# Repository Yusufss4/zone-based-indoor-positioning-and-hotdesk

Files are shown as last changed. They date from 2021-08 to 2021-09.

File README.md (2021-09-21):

[][contributors-url] [][forks-url] [][stars-url] [][issues-url]

<!-- PROJECT LOGO -->
<br/>
<p align="center">
  <a href="https://github.com/Yusufss4/Academy2021">
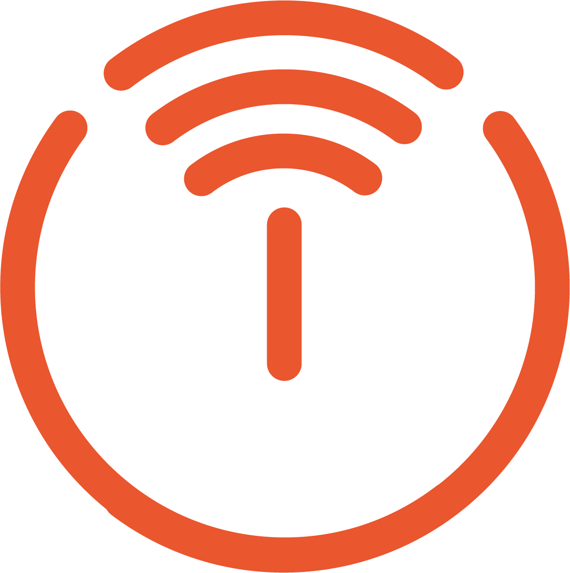
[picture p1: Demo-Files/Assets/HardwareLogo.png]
    
  </a>
  <h1 align="center">Intership Project Indoor Positioning and Hotdesk</h1>
  <p align="center">
    Borda Academy 2021 Project Co-Working Smart Office Hardware Part
    <br/>
    <a href="https://youtu.be/FV2so5sVpH8">Watch Video</a>
    ·
    <a href="https://github.com/Yusufss4/Academy2021/issues">Report Bug</a>
    ·
    <a href="https://github.com/Yusufss4/Academy2021/issues">Request Feature</a>
  </p>
   <p align="center">
    Index
    <br/>
    <a href="#about-the-project">About the Project</a>
    ·
    <a href="#products">Products</a>
    ·
    <a href="#Required-Parts-(BOM)">Part List</a>
        ·
    <a href="#How-to-Build-and-Run">How to Run</a>
            ·
      <a href="#MQTT-Connections-/-Topics">MQTT</a>
            ·
    <a href="#-Team-Behind-the-Hardware">Team</a>
  </p>
</p>

# About the Project

In this project there are three different task in the hardware section. These are;

 1. Capacity Calculation Per Room. Detecting a person if they are in the room and send information according to that.
 2. Capacity Calculation Per Office. Detecting a person if they are in the office or not using gateways. 
 3. Hotdesk and Meeting Room Scheduling. Controlling e-papers according to the information coming from the server. 
<p align="center">
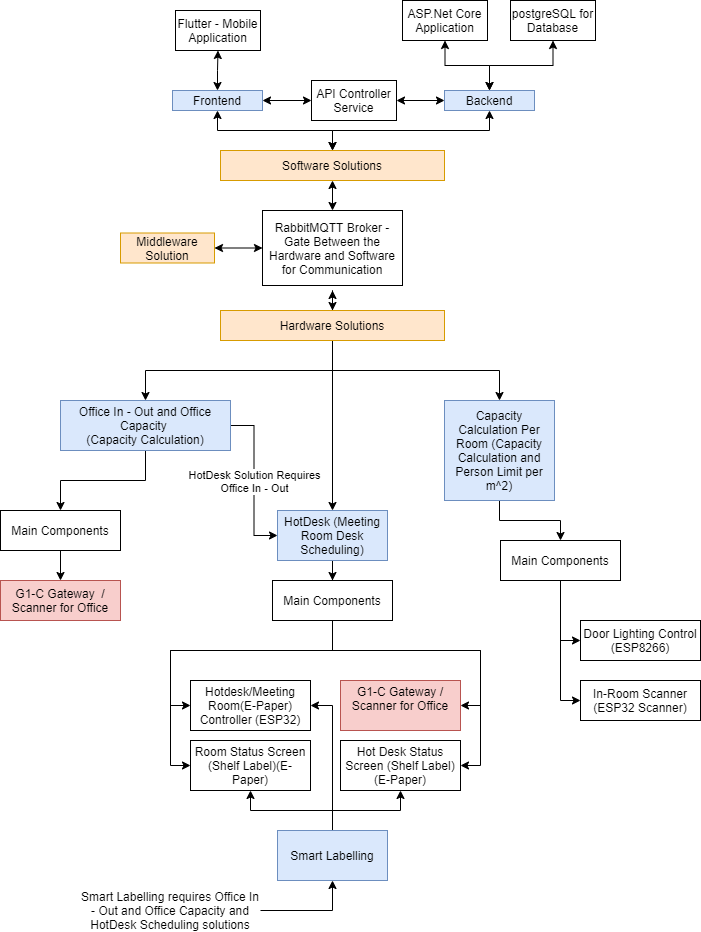
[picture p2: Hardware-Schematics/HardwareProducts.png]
Project Diagram

</p>

# Products

There are five different products in the project but only four of them can be coded and one of them can be only configured. 

## ESP32 In Room Scanner

### Explanation
ESP32 - In Room Scanner first scans the bluetooth devices and creates a buffer filled with RSSI signals and MAC addresses of the scanned devices. Later duplicate signals are being averaged and removed from the buffer and passed to the new buffer. Later in the publish MQTT function this buffer is transformed to JSON format and sent along with the MAC address of the device itself to differentiate the rooms (devices) from each other. This information will be processed by the server application and with the threshold value determined for each room the server will decide if the person is in the room and if it is in the room which person it is and send the number of people in the room information to the /nrom topic.

### Connection Diagram
<p align="center">
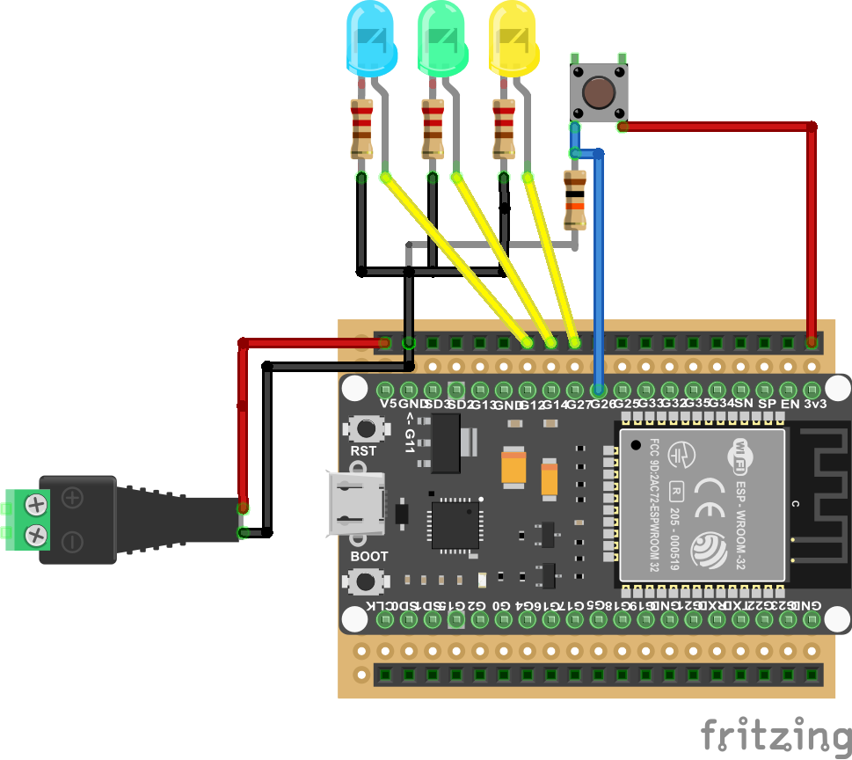
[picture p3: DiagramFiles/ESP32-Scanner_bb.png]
Connection Diagram
 
 </p>

### Box Design
<p align="center">
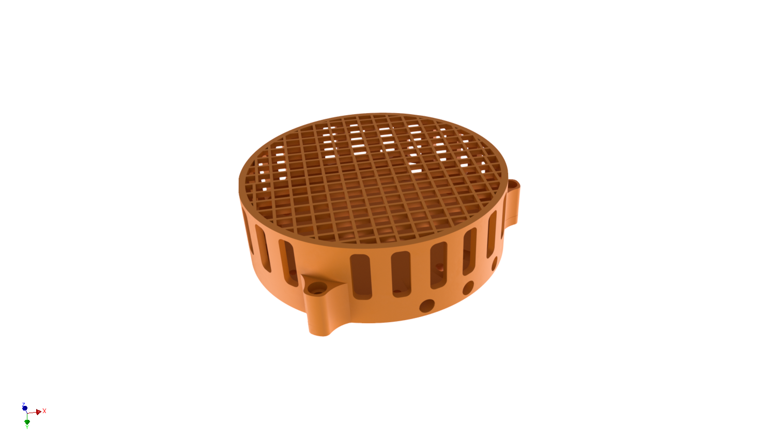
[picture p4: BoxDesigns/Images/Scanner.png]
Box Design

</p>

### Product
<p align="center">
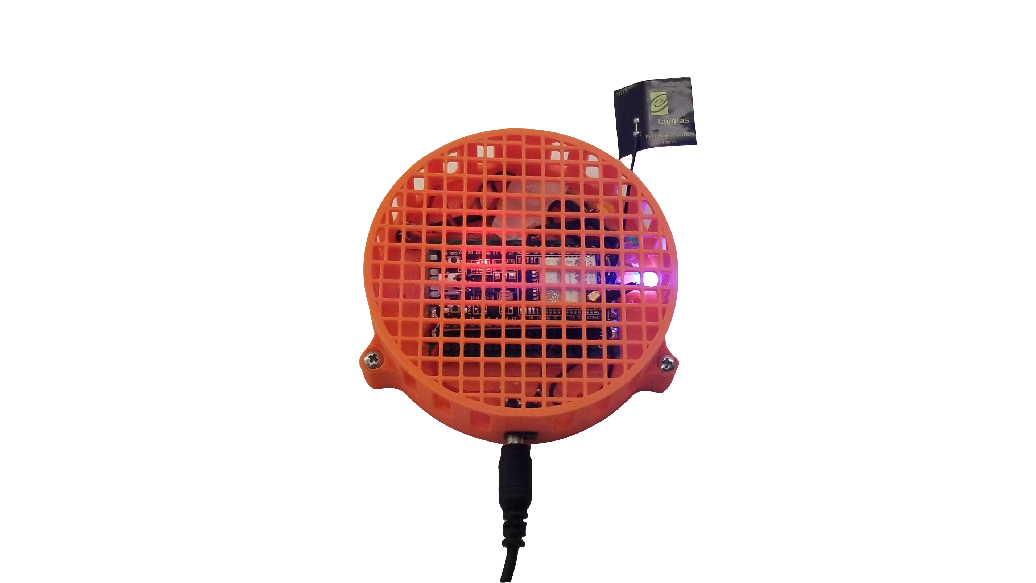
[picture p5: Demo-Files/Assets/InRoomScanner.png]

</p>
 
## ESP8266 Door Lighting Controller

ESP8266 always listens to the topic /nrom and whenever a message comes first by looking at the MAC addresses sent with the message it decides if the message is intended for it or not. If it is intended for that specific device according to the number of people information in the message it lights the NeoPixel LEDs. If the capacity is reached all LEDs will light in the color of red.

### Connection Diagram
<p align="center">
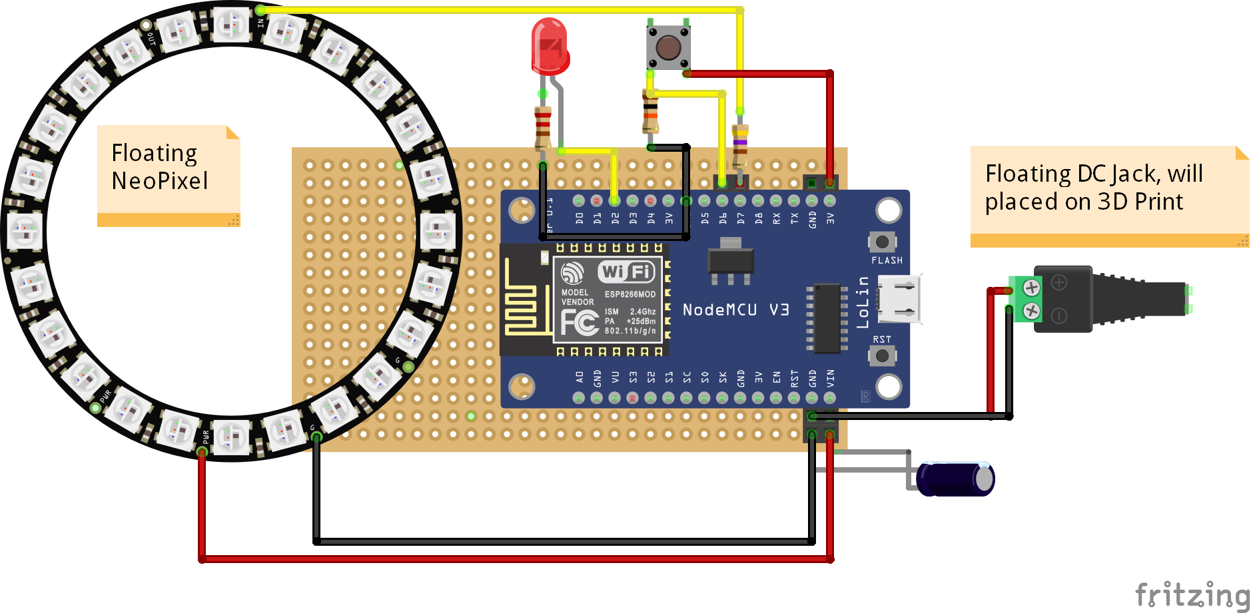
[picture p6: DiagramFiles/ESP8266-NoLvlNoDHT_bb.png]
ESP8266 Door Lighting Controller Connection Diagram
 
 </p>

### Box Design
<p align="center">
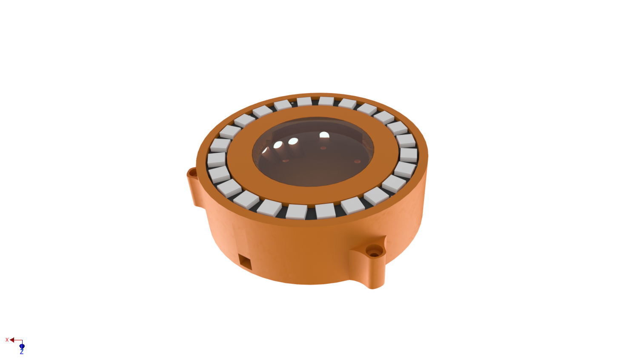
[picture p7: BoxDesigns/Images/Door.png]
ESP8266 Door Lighting Controller Box Design
 
</p>

### Product
<p align="center">
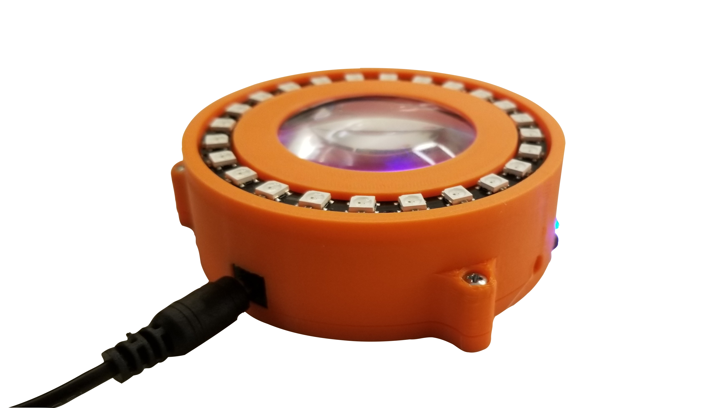
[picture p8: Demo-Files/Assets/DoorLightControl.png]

</p>

## ESP32 E-Paper Controller

E-paper controller ESP32 constantly listens to the publishments coming to the MQTT topic to which it is subscribed. When there is Publishment, it runs the bluetooth functions and does a scan. When it matches the UUID advertised by the shelf label with the UUID data received by MQTT, it establishes a connection with the shelf label. If the connection is successful, it sends the data to the electronic shelf label. If not, it will scan again and try to connect. MQTT sends a warning message to the broker if it cannot find a UUID value to match by scanning. 

### Connection Diagram
<p align="center">
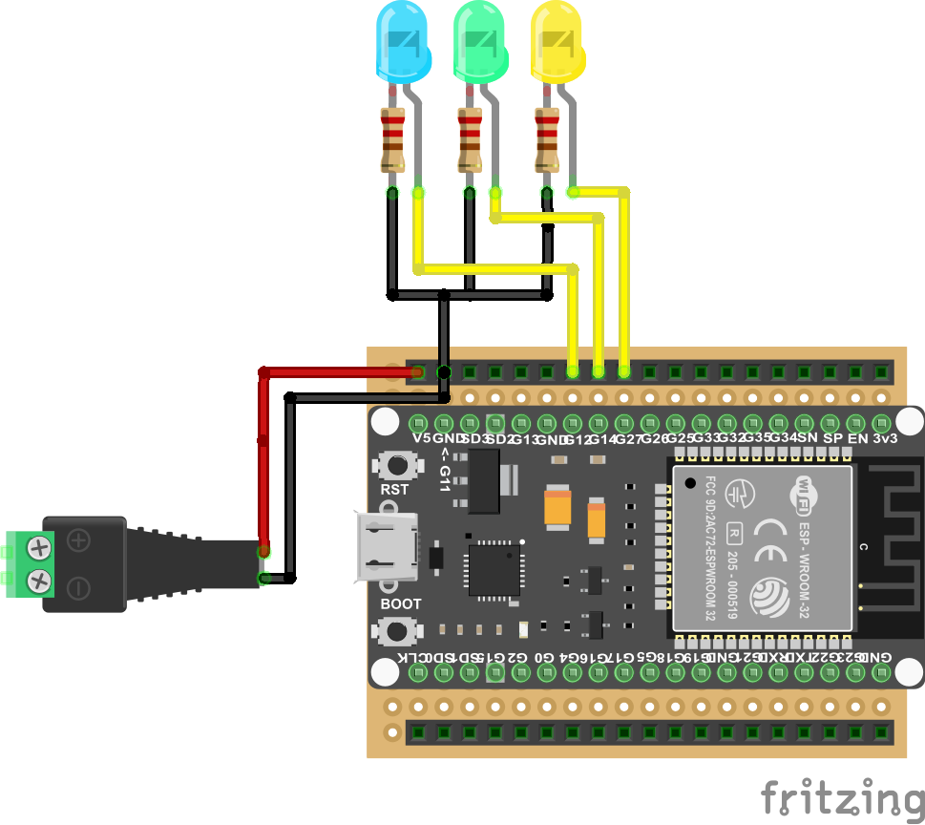
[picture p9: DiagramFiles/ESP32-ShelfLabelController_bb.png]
Connection Diagram
 
  </p>

### Box Design
<p align="center">
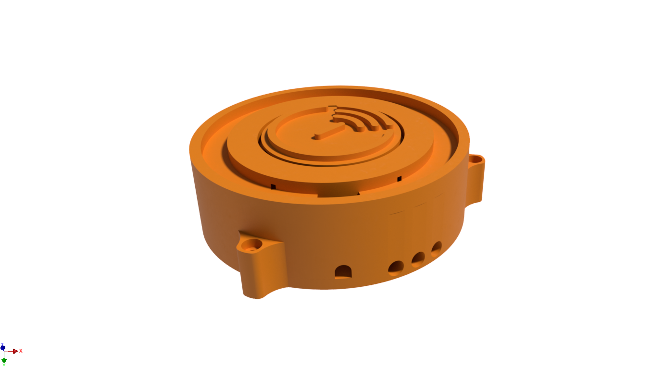
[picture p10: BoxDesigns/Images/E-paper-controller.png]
Box Design

 </p>

### Product
<p align="center">
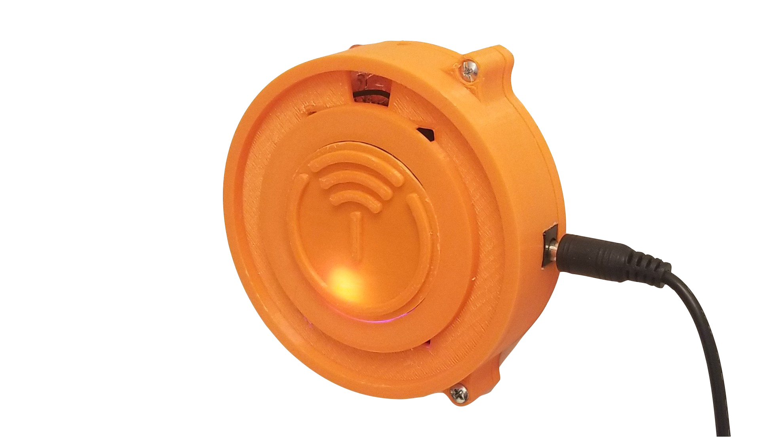
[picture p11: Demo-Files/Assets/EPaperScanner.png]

</p>

## E-Paper

Electronic Shelf Label is ready for a connection request by ESP32 by constantly making advertisements. The shelf labels used for the hot desk have two different screens. Reserved and Available screens. According to the data received by ESP32, the shelf label display is updated. The shelf labels used for the Meeting Room also have two different screens. Busy and Next event screens. According to the data received by ESP32, the shelf label display is updated.
### Screen Design
<p align="center">
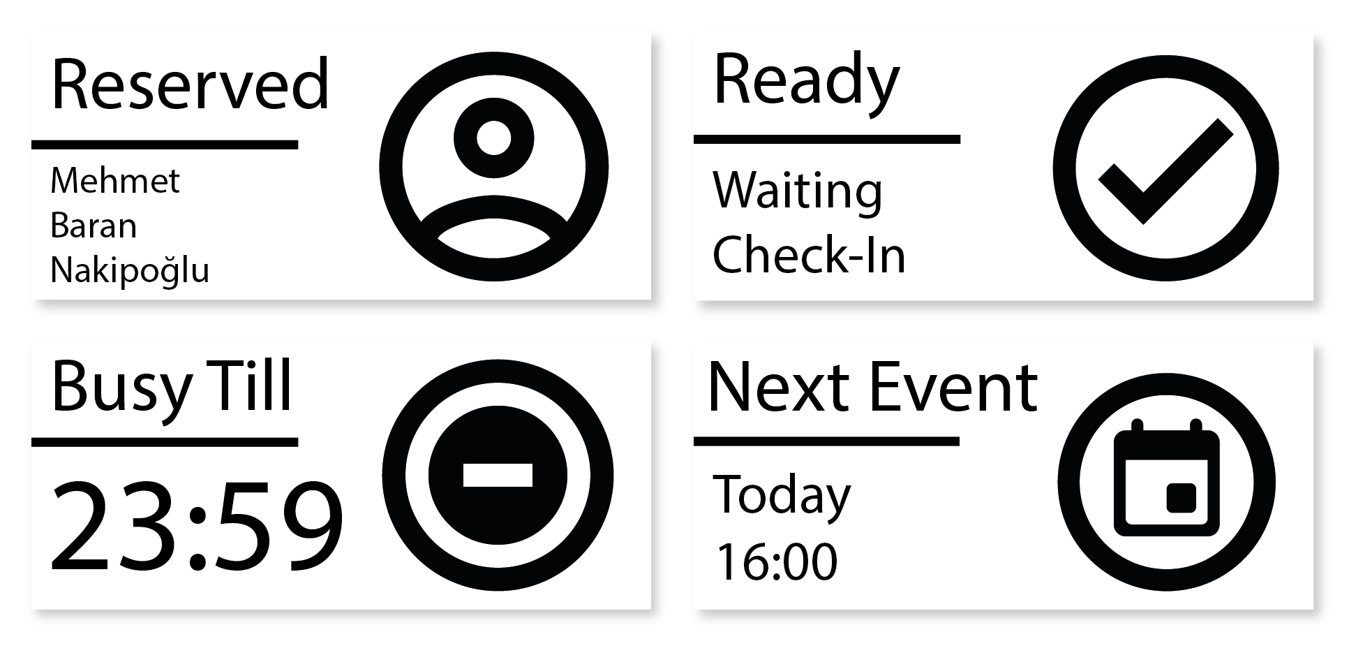
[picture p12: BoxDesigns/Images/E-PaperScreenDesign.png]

</p>

<!---
![resim](https://user-images.githubusercontent.com/44584158/132695852-41f96476-604e-4485-b37b-de702ea20266.png)

### Connection Diagram
<p align="center">
 <img src="images/logo.png" alt="E-Paper Connection Diagram" width="400">
 </p>
 -->

### Box Design
<p align="center">
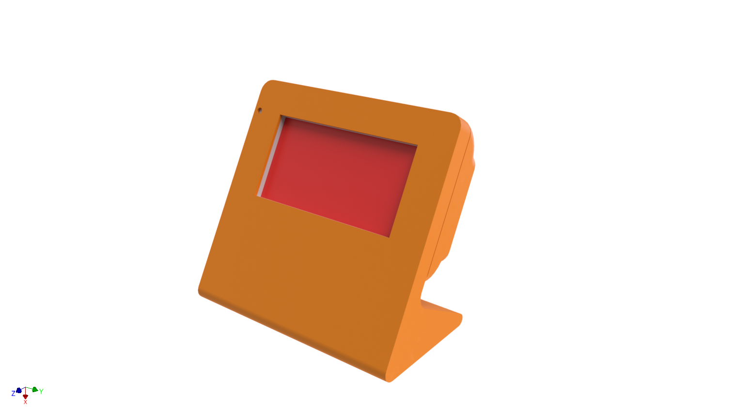
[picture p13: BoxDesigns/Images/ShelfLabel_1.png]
E-Paper Box Design

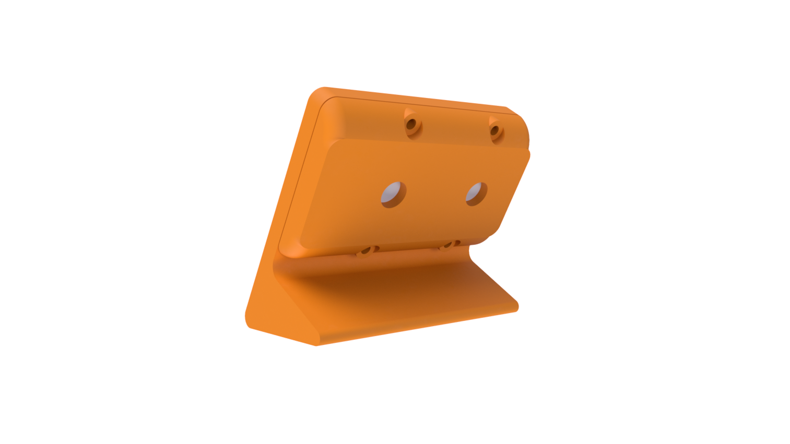
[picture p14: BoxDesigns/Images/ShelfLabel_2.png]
E-Paper Box Design

</p>

### Product
<p align="center">
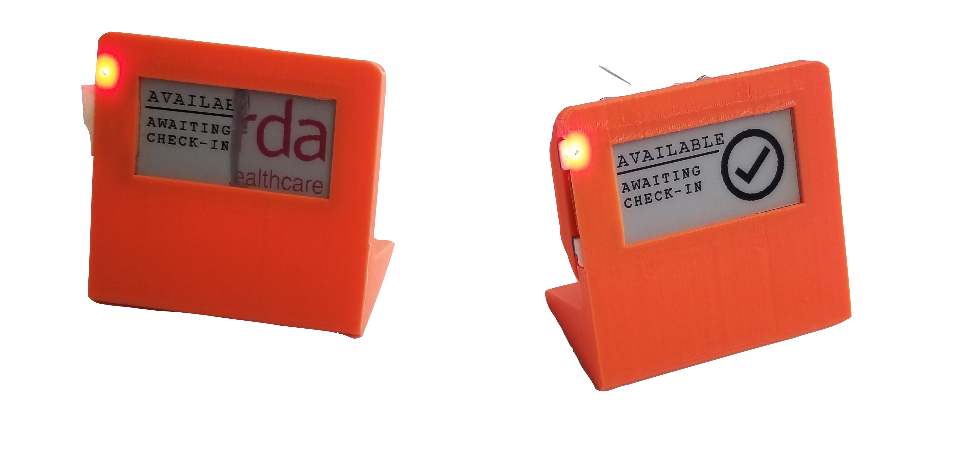
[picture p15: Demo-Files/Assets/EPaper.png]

</p>

# Required Parts (BOM)

All the required parts are determined for 2 Hotdesk, 2 Beacon, 2 Room and one Office. If you want to increase the number of rooms that you want to install you have to multiply the ESP8266 Door Light and ESP32 In Room Scanner equipments by two. Each room has one ESP8266 and one ESP32.

## BOM For ESP8266 Door Lighting Controller

| Name | How | Piece | How Many | Where |
|---|---|---|---|---|
| ESP32 | Main Controller | 1 | 1 Per Room/Device | Near the door |
| NeoPixel 24 Ring | Capacity Indicator | 1 | 1 Per Room/Device | Near the door |
| 5V Adapter | Power for ESP32 | 1 | 1 Per Room/Device | Near the door |
| 4x6cm Soldering Prototype Board | ESP32 Placement | 1 | 1 Per Room/Device | Near the door |
| 470R 1/4W Resistor | NeoPixel Signal Resistor | 1 | 1 Per Room/Device | Near the door |
| 5.5x2.21mm DC Power Jack | Power for ESP32 | 1 | 1 Per Room/Device | Near the door |
| 1x40 Male Header 80 Pin 90 Degree | ESP32 Placement | 1 | 1 Per Room/Device | Near the door |
| 1x40 Female Header 40 Pin 180 Degree | ESP32 Placement | 1 | 1 Per Room/Device | Near the door |
| 1000uF Capacitor | NeoPixel Current Protection | 1 | 1 Per Room/Device | Near the door |
| 6x6x5 Push Button | WiFi Access Point Reset | 1 | 1 Per Room/Device | Near the door |
| Blue LED | MQTT Indicator | 1 | 1 Per Room/Device | Near the door |
| 3D Printed Box Upper-Piece | Box Upper | 1 | 1 Per Room/Device | Near the door |
| 3D Printed Box Lower-Piece | Box Base Plate | 1 | 1 Per Room/Device | Near the door |
| 50mm Lens or Glass | To See Onboard Leds | 1 | 1 Per Room/Device | Near the door |

## BOM For ESP32 - In Room Scanner
| Name | How | Piece | How Many | Where |
|---|---|---|---|---|
| ESP32 DevkitV4 | Main Controller | 1 | 1 Per Room/Device | Inside the Room |
| ESP32 Taoglas 2.4Ghz | External Antenna for ESP32 | 1 | 1 Per Room/Device | Inside the Room |
| 5V Adapter | Power for ESP32 | 1 | 1 Per Room/Device | Inside the Room |
| 4x6cm Soldering Prototype Board | ESP32 Placement | 1 | 1 Per Room/Device | Inside the Room |
| 5.5x2.21mm DC Power Jack | Power for ESP32 | 1 | 1 Per Room/Device | Inside the Room |
| 1x40 Male Header 80 Pin 90 Degree | ESP32 Placement | 1 | 1 Per Room/Device | Inside the Room |
| 1x40 Female Header 40 Pin 180 Degree | ESP32 Placement | 1 | 1 Per Room/Device | Inside the Room |
| 6x6x5 Push Button | WiFi Access Point Reset | 1 | 1 Per Room/Device | Inside the Room |
| LEDs | Status LEDs | 3 | 1 Per Room/Device | Inside the Room |
| 3D Printed Box Upper-Piece | Box Upper | 1 | 1 Per Room/Device | Inside the Room |
| 3D Printed Box Lower-Piece | Box Base Plate | 1 | 1 Per Room/Device | Inside the Room |

## BOM For ESP32 - E-Paper Controller
| Name | How | Piece | How Many | Where |
|---|---|---|---|---|
| ESP32 DevkitV4 | Main Controller | 1 | 1 Per Room/Device | Inside the Room |
| 5V Adapter | Power for ESP32 | 1 | 1 Per Room/Device | Inside the Room |
| 4x6cm Soldering Prototype Board | ESP32 Placement | 1 | 1 Per Room/Device | Inside the Room |
| 5.5x2.21mm DC Power Jack | Power for ESP32 | 1 | 1 Per Room/Device | Inside the Room |
| 1x40 Male Header 80 Pin 90 Degree | ESP32 Placement | 1 | 1 Per Room/Device | Inside the Room |
| 1x40 Female Header 40 Pin 180 Degree | ESP32 Placement | 1 | 1 Per Room/Device | Inside the Room |
| 6x6x5 Push Button | WiFi Access Point Reset | 1 | 1 Per Room/Device | Not Added Yet |
| LEDs | Status LEDs | 3 | 1 Per Room/Device | Not Added Yet |
| 3D Printed Box Upper-Piece | Box Upper | 1 | 1 Per Room/Device | Inside the Room |
| 3D Printed Box Lower-Piece | Box Base Plate | 1 | 1 Per Room/Device | Inside the Room |

## Other Parts
| Name | How | Piece | How Many | Where |
|---|---|---|---|---|
| MTag2901 2.9" ESL Tag  | Room Status Screen | 1 | 1 per Room | Near the door |
| MTag2901 2.7" ESL Tag  | Hotdesk Status Screen | 2 | 1 per Table | On the table |
| CR2450 3V Battery | Battery for ESL | 2 | 2 per ESL | In ESL |
| CR2477 3V Battery | Battery for E7 Beacon | 2 | 1 per People | In Beacon |
| G1-C Gateway | BLE Office Covarage | 1 | 1 per Office | Middle of Office |
| E7 Plus Beacon | BLE Advertisement | 2 | 1 per People | On People's Pocket |
| Extension cable | To Extend Power | 2 | As you require | Near Power |

# How to Build and Run

## ESP32 In-Room Scanner and ESP8266 Door Light Controller
1. You can run the project without all the Leds, power adapters, buttons, cables etc. just by uploading code to the necessary controller boards like ESP32 and ESP8266.
2. Download the code for each device. Each document is divided in the files too.
3. Download the ESP32 and ESP8266 Packages for board manager in Arduino IDE.
4. For ESP32 click Tools->Partition Scheme->Huge APP (3MB/No OTA) so that code can compile.
5. You have to use a MQTT Broker for publishing and subscribing topics. From the MQTT Config change the connections to whatever broker you are using.
6. If you are using a broker that requires a certificate uncomment the certificate and transform the **WifiClient** to **WiFiClientSecure**so that ESP32 or ESP8266 can transfer the certificates. ,
7. Pull the Button Pin to the 3.3V if you did not connect the button so that WiFi manager does not reset the WiFi credentials.
8. ESP32 In-Room Scanner and ESP8266 uses WifiManager so to connect the devices to the WiFi, if the device is not connected the Access Point will be opened, first you should connect to the wifi network created by device, name will be Fora - [Mac Address of Device] and later a web page application will be opened if you connect to that Access Point. Later you can connect to any wifi.
9. After connecting both ESP32 and ESP8266 to WiFi and MQTT Broker you can test the device using the MQTTLens application.
10. If you made all the connections like buttons, leds, neopixel etc. you can test the PCB by running the code PCBTester in the Demo files.

## ESP32 E-Paper Controller and E-Paper

1.
2.

# MQTT Connections / Topics

 - Topic and Data Type documentation can be reached from [here.](https://docs.google.com/document/d/1uNCvFoLJsAC_Qh4L8_6ozjhal6APVGUYTeoTuyXoGE8/edit?usp=sharing)
 - To connect the devices you have to use a MQTT Broker. For the connections steps please follow How to Run steps.
>Some of the alternatives for the MQTT Broker: 
> - Deployed RabbitMQ 
> - Adafruit IO
> - EMQX
> - HiveMQ (Not Stable)

General Diagram showing the communication can be seen below.
<p align="center">
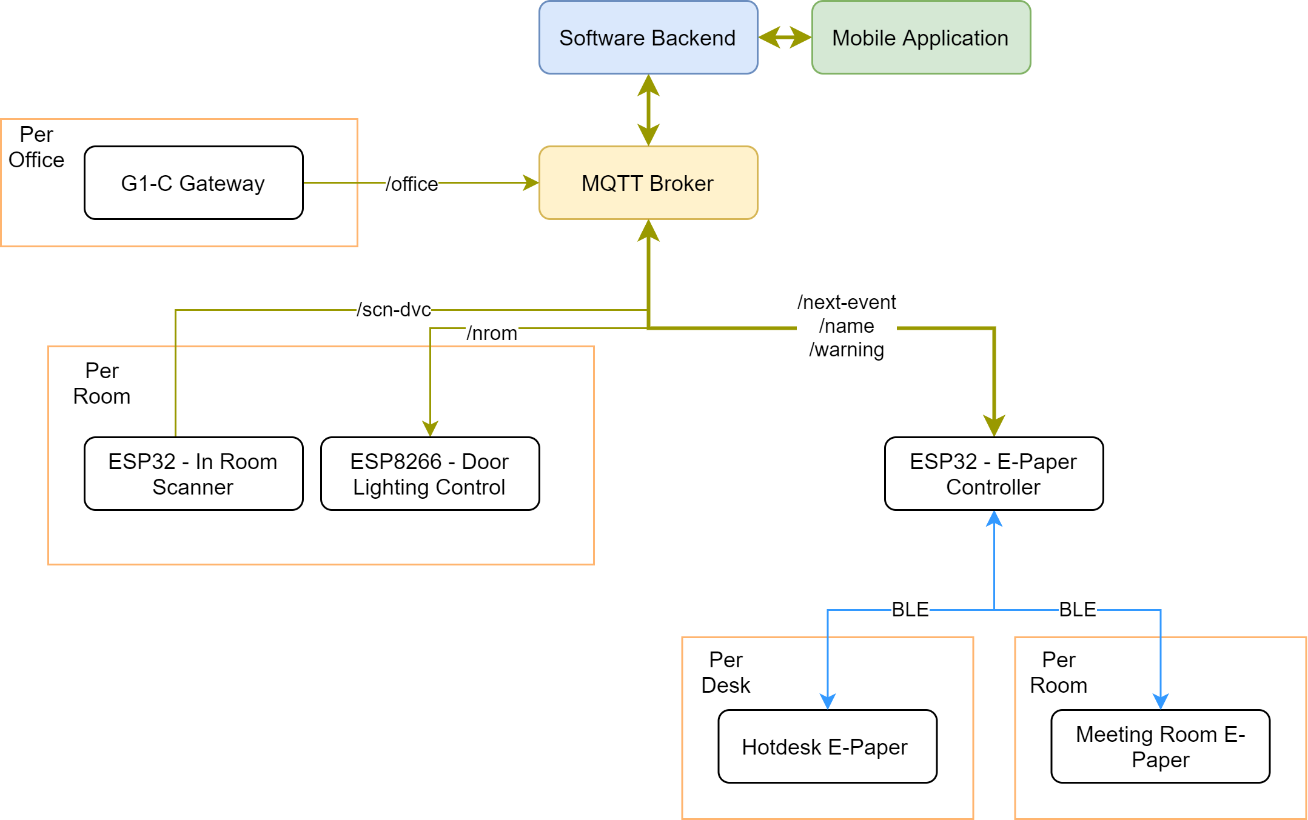
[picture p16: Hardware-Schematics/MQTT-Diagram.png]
MQTT Diagram

</p>

# Team Behind the Hardware

<p align="center">
<a href="https://www.linkedin.com/in/yusufss/">
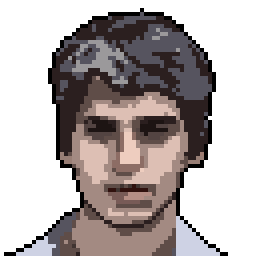
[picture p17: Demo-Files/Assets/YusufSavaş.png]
Yusuf Savaş
  </a> 
 <a href="https://www.linkedin.com/in/utkuurkun/">
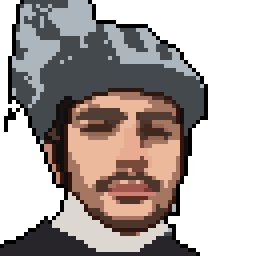
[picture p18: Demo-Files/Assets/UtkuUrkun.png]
Utku Urkun
   </a>
  <a href="https://www.linkedin.com/in/ata-korkusuz-77707118b/">
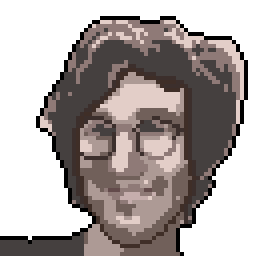
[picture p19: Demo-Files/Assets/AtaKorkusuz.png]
Ata Korkusuz
   </a>
</p>

<p align="center">
<a href="https://www.linkedin.com/in/berkay-arslan-3b9b95141/">
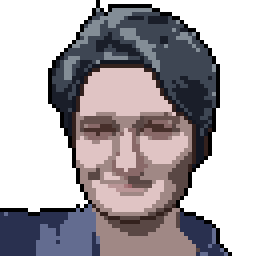
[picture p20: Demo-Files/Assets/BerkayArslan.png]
Berkay Arslan
   </a> 
  <a href="https://www.linkedin.com/in/zeynepbilge/">
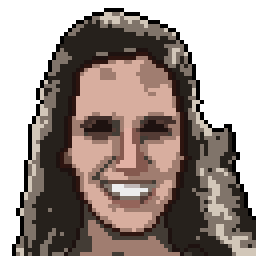
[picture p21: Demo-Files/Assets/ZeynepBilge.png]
Zeynep Bilge
   </a>
  <a href="https://www.linkedin.com/in/emine-acar-8036639b/">
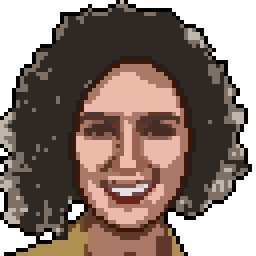
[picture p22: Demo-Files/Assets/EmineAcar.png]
Emine Acar
   </a>
</p>

<p align="center">
<a href="https://www.linkedin.com/in/eymen-topcuoglu/">
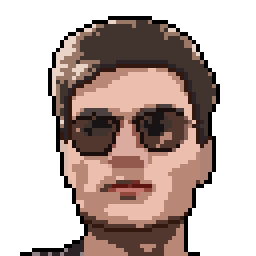
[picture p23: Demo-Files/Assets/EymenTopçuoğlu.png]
Eymen Topçuoğlu
   </a>
</p>

<!-- MARKDOWN LINKS & IMAGES -->
<!-- https://www.markdownguide.org/basic-syntax/#reference-style-links -->
[contributors-shield]: https://img.shields.io/github/contributors/Yusufss4/Academy2021.svg?style=for-the-badge
[contributors-url]: https://github.com/Yusufss4/Academy2021/graphs/contributors
[forks-shield]: https://img.shields.io/github/forks/Yusufss4/Academy2021.svg?style=for-the-badge
[forks-url]: https://github.com/Yusufss4/Academy2021/network/members
[stars-shield]: https://img.shields.io/github/stars/Yusufss4/Academy2021.svg?style=for-the-badge
[stars-url]: https://github.com/Yusufss4/Academy2021/stargazers
[issues-shield]: https://img.shields.io/github/issues/Yusufss4/Academy2021.svg?style=for-the-badge
[issues-url]: https://github.com/Yusufss4/Academy2021/issues
[license-shield]: https://img.shields.io/github/license/Yusufss4/Academy2021.svg?style=for-the-badge
[license-url]: https://github.com/Yusufss4/Academy2021/blob/master/LICENSE.txt
[linkedin-shield]: https://img.shields.io/badge/-LinkedIn-black.svg?style=for-the-badge&logo=linkedin&colorB=555
[linkedin-url]: https://linkedin.com/in/yusufss
[product-screenshot]: images/screenshot.png

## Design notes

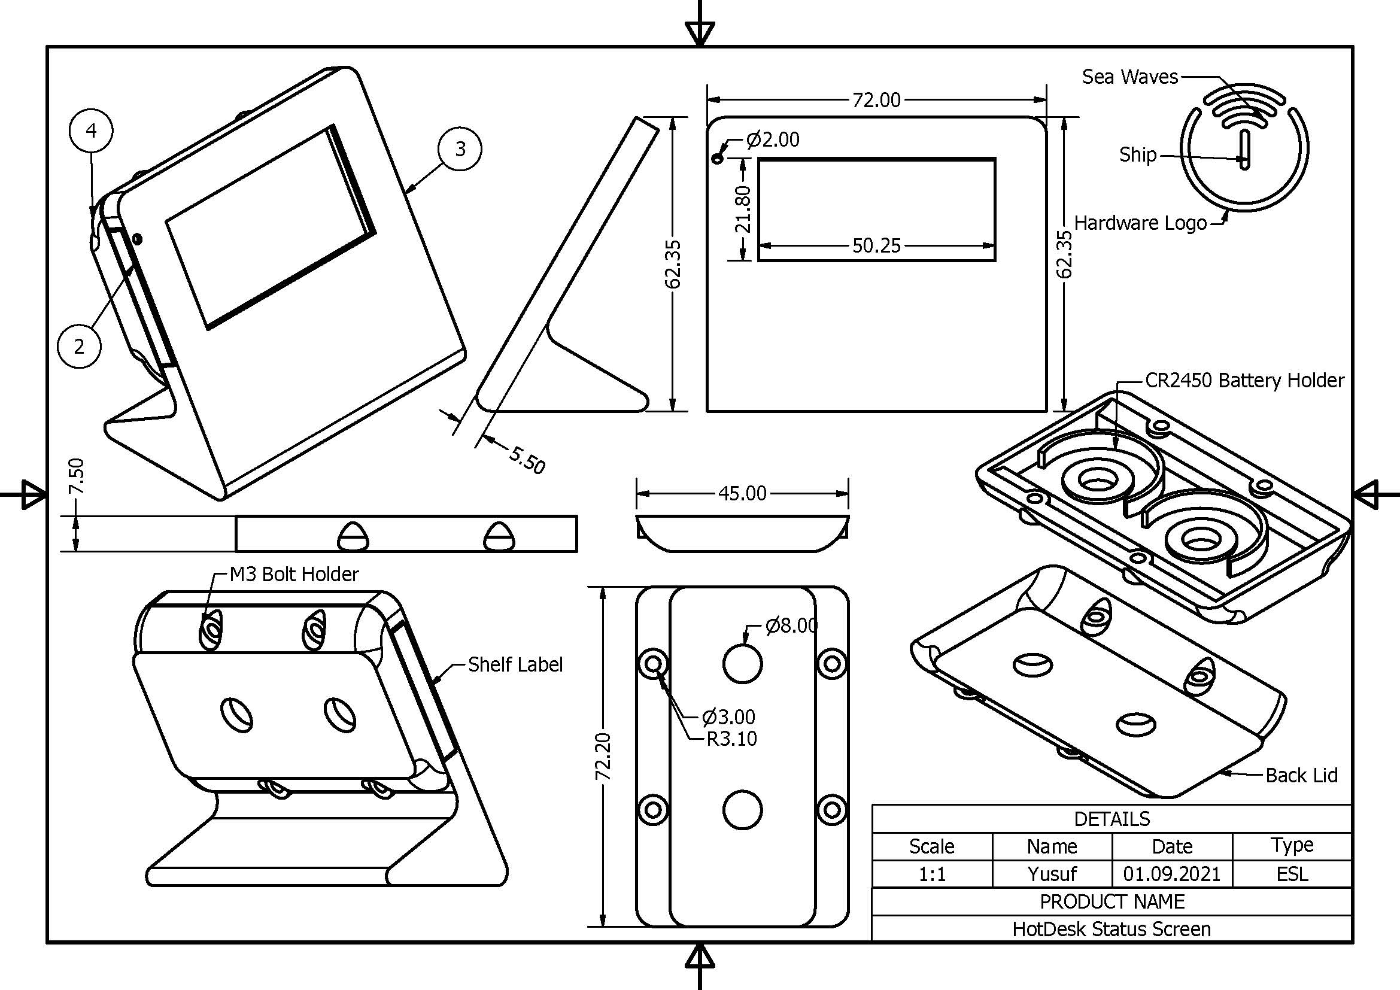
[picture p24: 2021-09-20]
BoxDesigns/Images/ShelfLabel.jpg

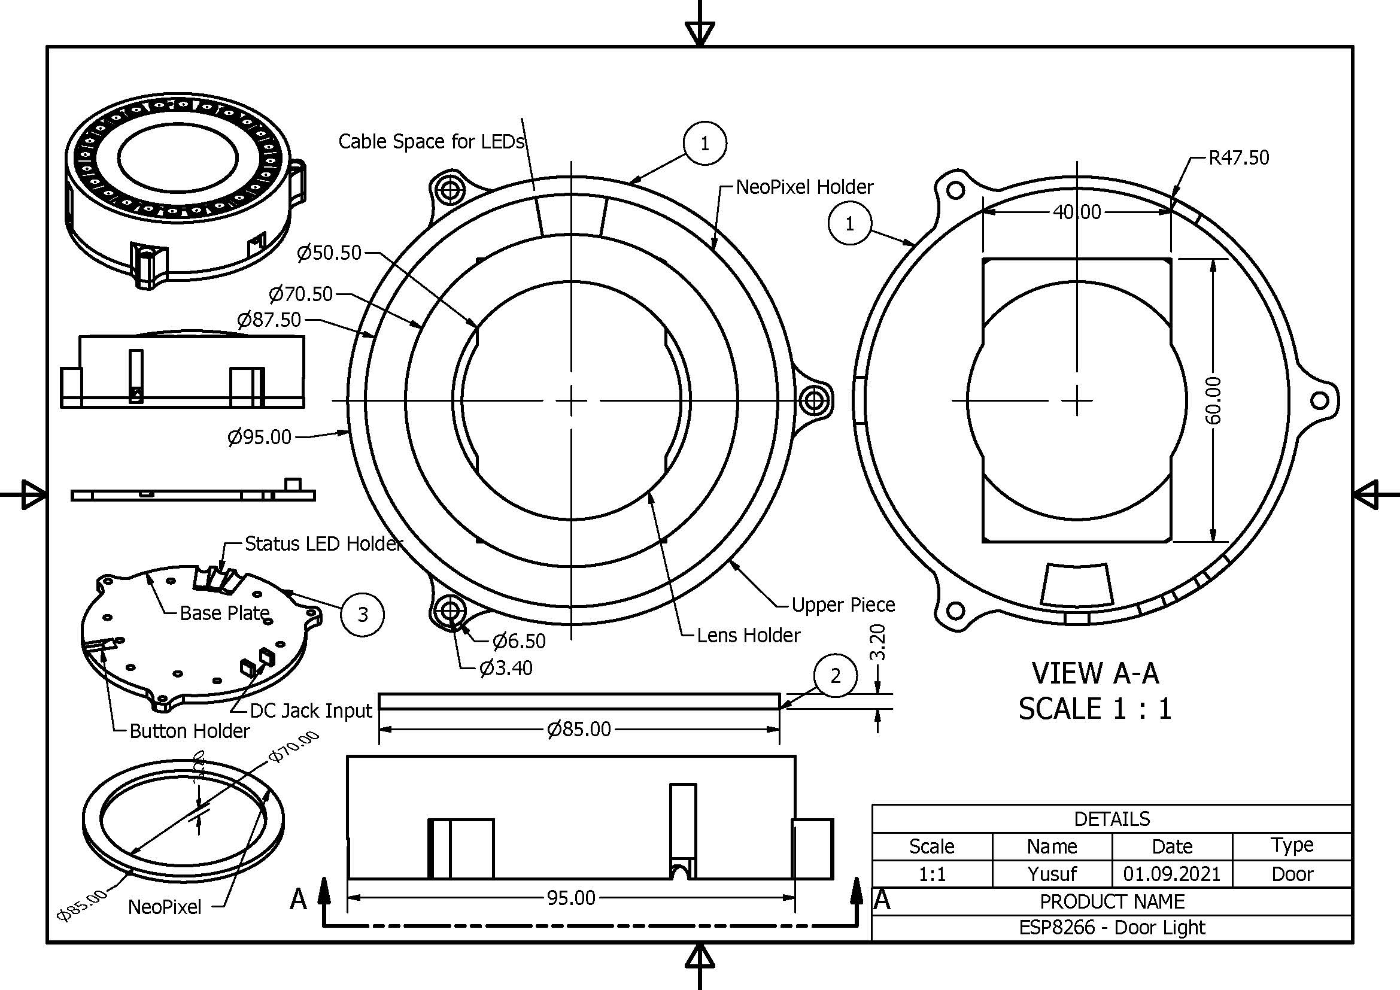
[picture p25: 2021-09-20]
BoxDesigns/Images/ESP8266-Door.jpg

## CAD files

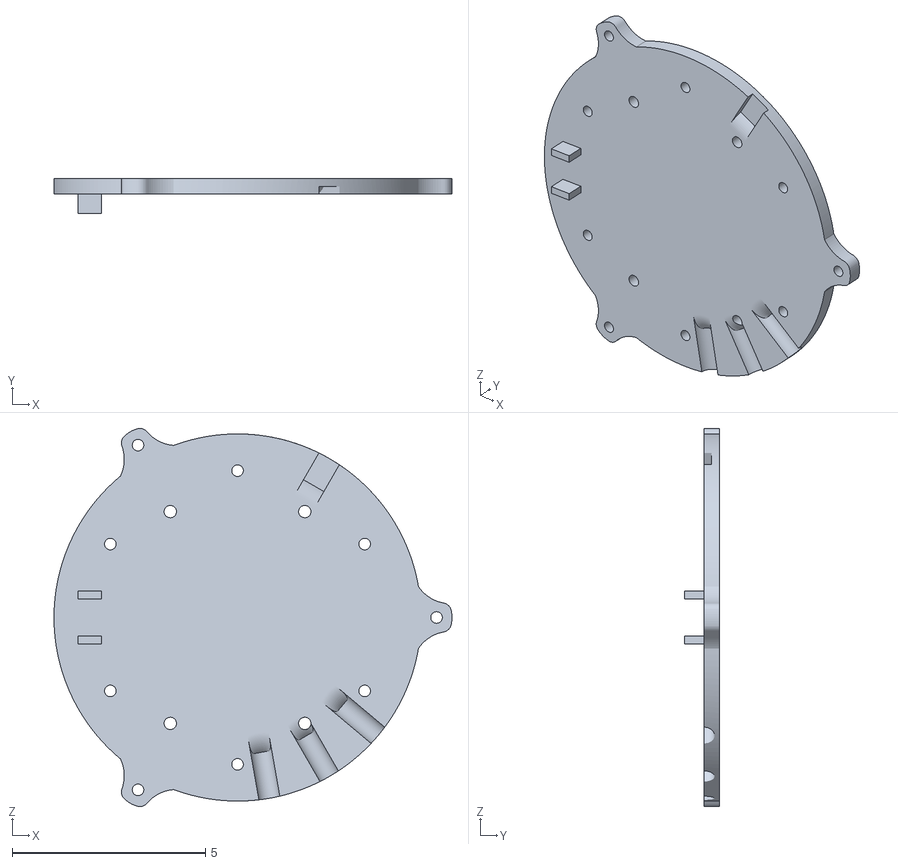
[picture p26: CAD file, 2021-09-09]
BoxDesigns/ESP32-Scanner/Scanner-BottomPart.stl
10.3 x 0.9 x 9.79

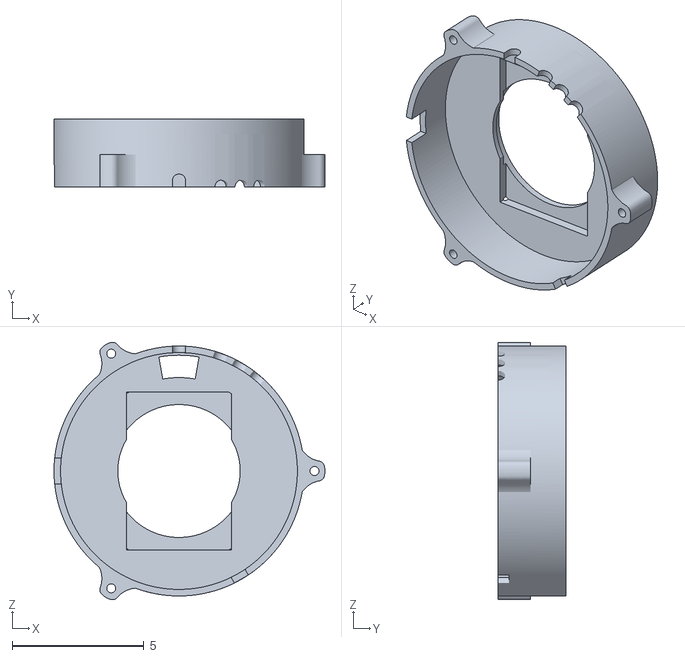
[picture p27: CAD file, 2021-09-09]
BoxDesigns/ESP8266-Door/Door-TopPart_MirrorV3.stl
10.3 x 2.60 x 9.79

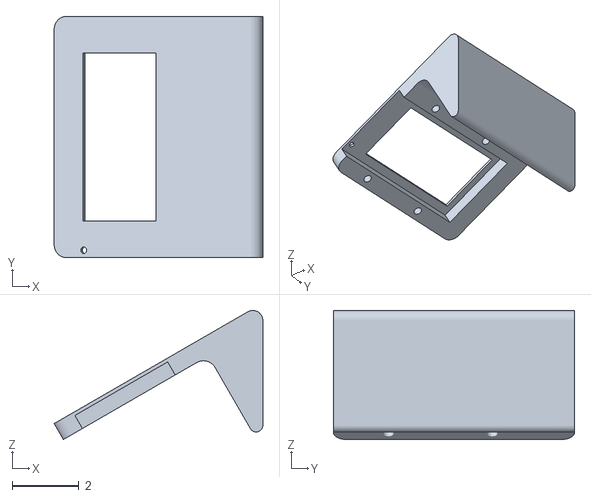
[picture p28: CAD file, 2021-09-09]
BoxDesigns/ShelfLabel/ShelfLabelStandV2.stl
6.24 x 7.20 x 3.86

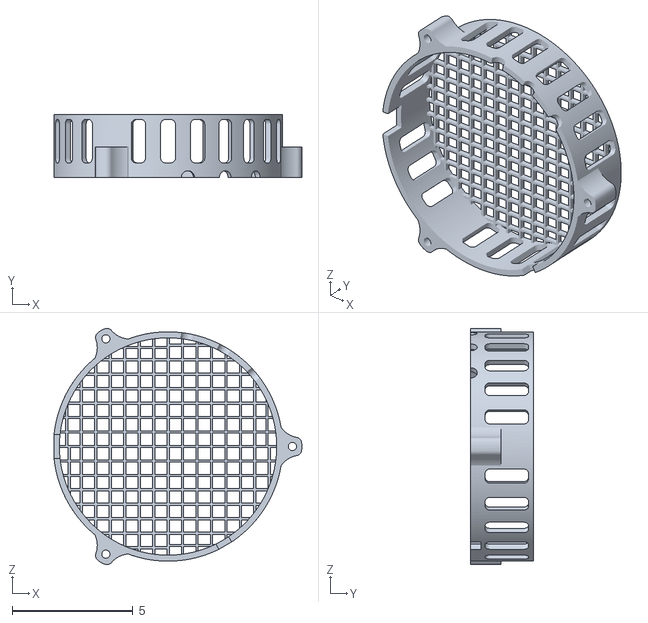
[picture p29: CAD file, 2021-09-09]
BoxDesigns/ESP32-Scanner/Scanner-TopPartV2_MirrorV2.stl
10.3 x 2.60 x 9.79

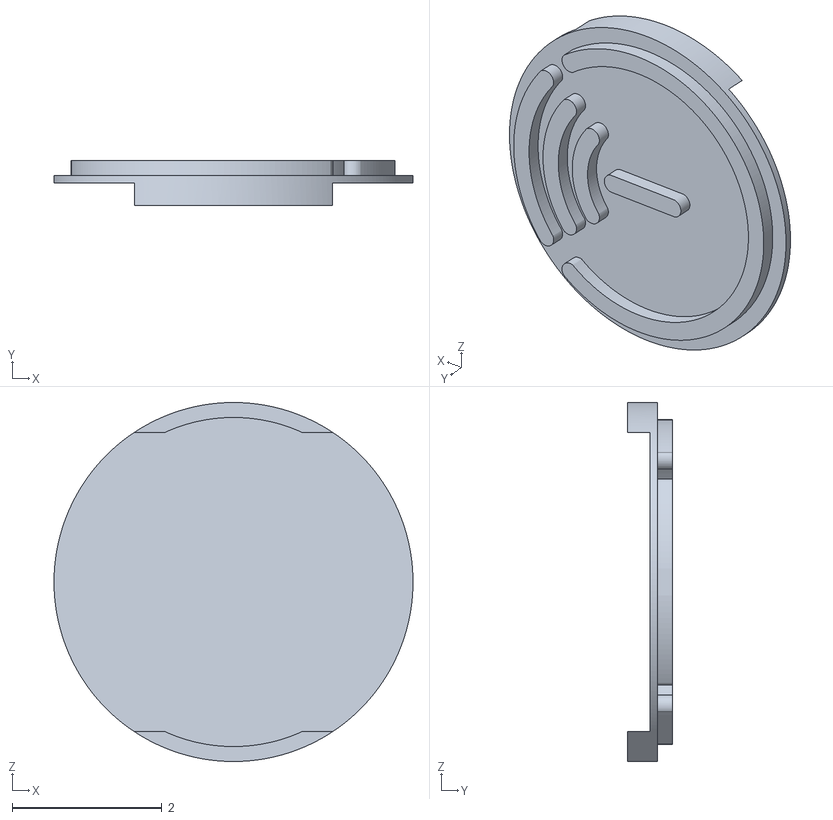
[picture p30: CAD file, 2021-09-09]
BoxDesigns/ShelfLabel/Scanner-Kapak.stl
4.80 x 0.6 x 4.80

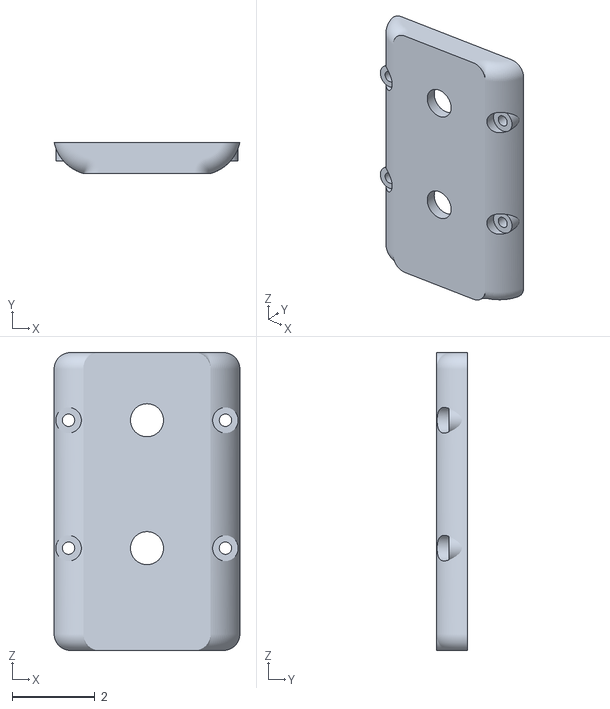
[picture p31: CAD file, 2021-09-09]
BoxDesigns/ShelfLabel/ShelfLabel-Kapak.stl
4.50 x 0.75 x 7.22

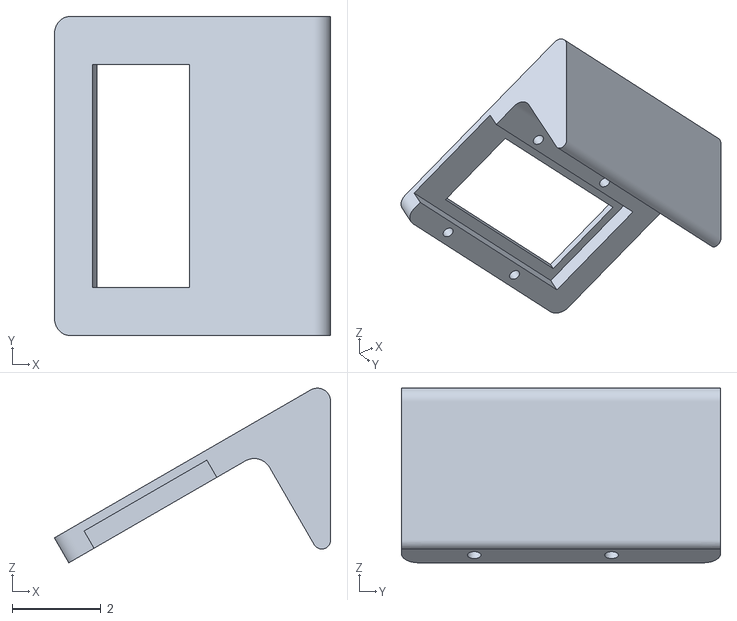
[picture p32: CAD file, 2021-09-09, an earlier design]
BoxDesigns/ShelfLabel/ShelfLabelStandV1.stl
6.24 x 7.20 x 3.94

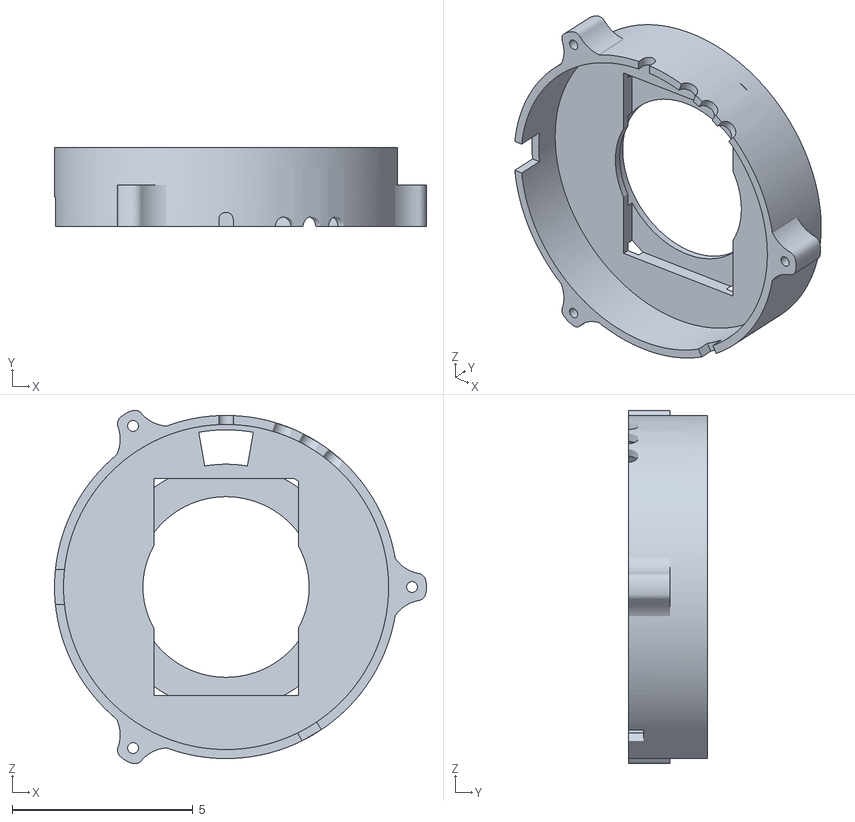
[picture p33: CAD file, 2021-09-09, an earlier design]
BoxDesigns/ESP8266-Door/Door-TopPart_MirrorV2.stl
10.3 x 2.20 x 9.79

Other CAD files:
BoxDesigns/ESP32-Scanner/Scanner-Assembly.dwg
BoxDesigns/ESP8266-Door/ESP8266-Door.dwg
BoxDesigns/ShelfLabel/ShelfLabel.dwg
BoxDesigns/ESP8266-Door/Door-BottomPart.stl
BoxDesigns/ESP32-Scanner/OldVersions/Scanner-Assembly.0004.dwg
BoxDesigns/ESP8266-Door/OldVersions/ESP8266-Door.0001.dwg
BoxDesigns/ShelfLabel/OldVersions/ShelfLabel.0002.dwg
BoxDesigns/ESP32-Scanner/OldVersions/Scanner-Assembly.0002.iam
BoxDesigns/ESP32-Scanner/OldVersions/Scanner-BottomPart.0004.ipt
BoxDesigns/ESP32-Scanner/OldVersions/Scanner-Kapak.0003.ipt
BoxDesigns/ESP32-Scanner/OldVersions/Scanner-TopPart.0016.ipt
BoxDesigns/ESP32-Scanner/OldVersions/Scanner-TopPartV2.0002.ipt
BoxDesigns/ESP32-Scanner/Scanner-Assembly.iam
BoxDesigns/ESP32-Scanner/Scanner-BottomPart.ipt
BoxDesigns/ESP32-Scanner/Scanner-Electronics.ipt
BoxDesigns/ESP32-Scanner/Scanner-TopPart.ipt
BoxDesigns/ESP32-Scanner/Scanner-TopPartV2.ipt
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

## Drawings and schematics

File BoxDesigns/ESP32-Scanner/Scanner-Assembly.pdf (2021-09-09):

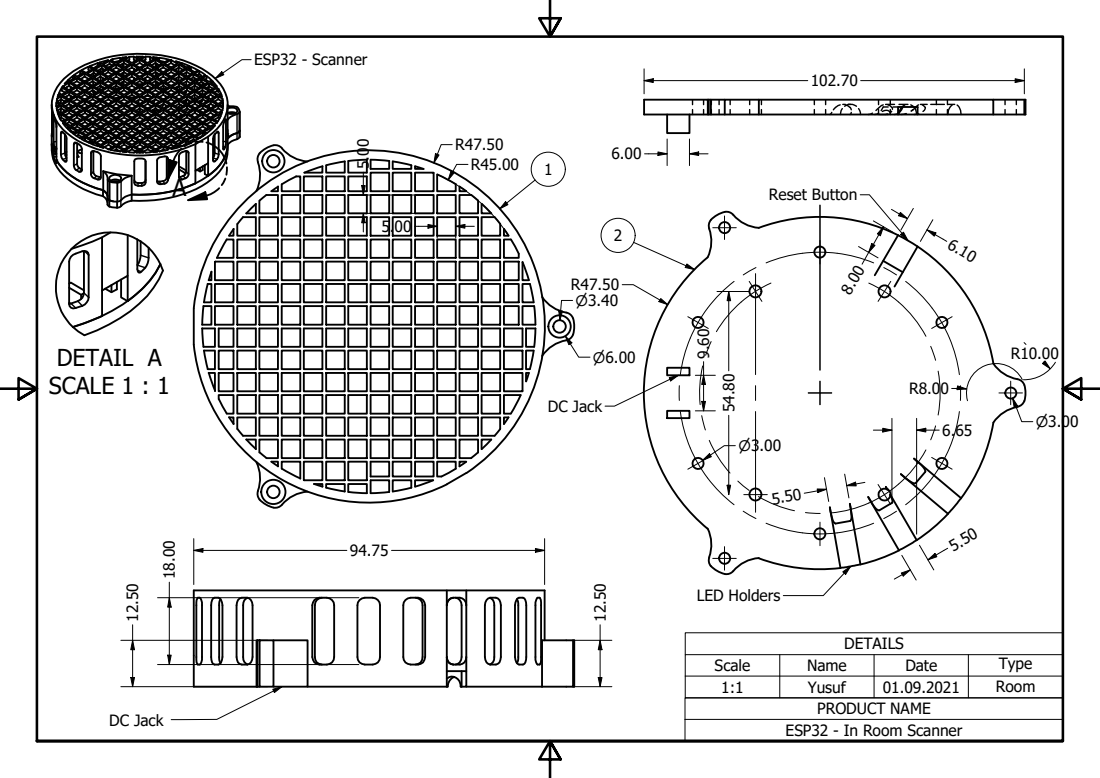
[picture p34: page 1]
DETAIL A SCALE 1 : 1; ESP32 - Scanner; LED Holders; DC Jack; Reset Button

Scale | Name | Date | Type
1:1 | Yusuf | 01.09.2021 | Room

PRODUCT NAME
ESP32 - In Room Scanner

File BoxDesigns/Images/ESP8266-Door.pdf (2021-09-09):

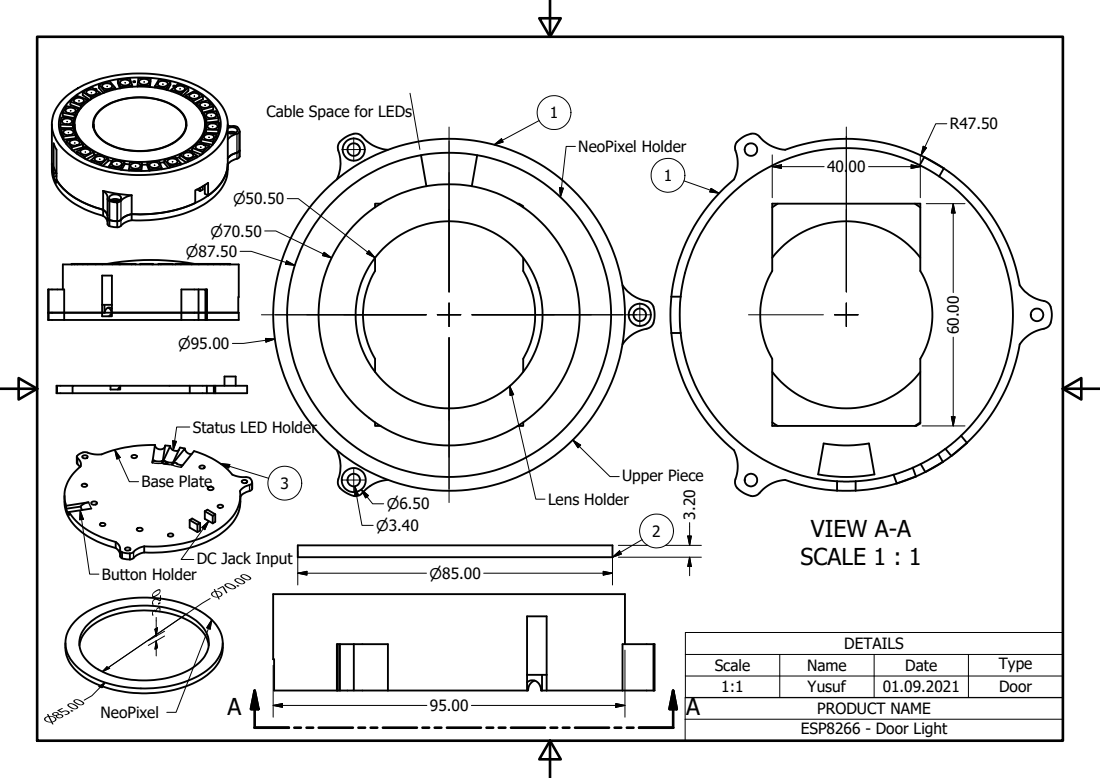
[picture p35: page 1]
VIEW A-A SCALE 1 : 1; DETAILS; PRODUCT NAME ESP8266 - Door Light; NeoPixel; Base Plate; Upper Piece; Lens Holder; NeoPixel Holder; Button Holder

Cable Space for LEDs

Status LED Holder

DC Jack Input

Scale | Name | Date | Type
1:1 | Yusuf | 01.09.2021 | Door

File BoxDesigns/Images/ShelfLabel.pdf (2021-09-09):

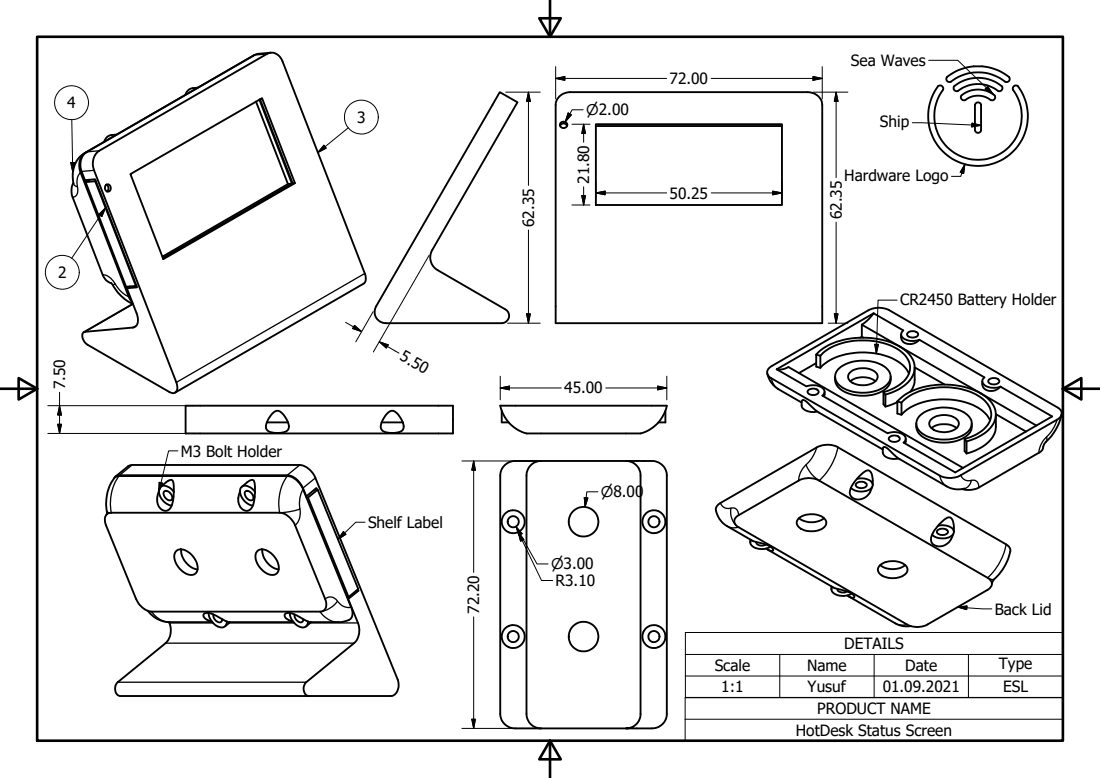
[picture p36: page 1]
DETAILS; CR2450 Battery Holder; Back Lid; Shelf Label; M3 Bolt Holder; Hardware Logo; Ship; Sea Waves

Scale | Name | Date | Type
1:1 | Yusuf | 01.09.2021 | ESL

PRODUCT NAME
HotDesk Status Screen

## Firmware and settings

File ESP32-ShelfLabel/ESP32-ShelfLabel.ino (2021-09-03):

//Change Config File to Connect the MQTT Broker and WiFi
#include <Arduino.h>
#include <WiFi.h>
#include <PubSubClient.h>
#include "MQTT_Config.h"
#include "BLEDevice.h"
#include <Dictionary.h>


//dictionary settings
#define _DICT_KEYLEN 40
#define _DICT_VALLEN 254

#define MQTT_LED 2
#define BLE_LED 12
#define WAR_LED 27

#define DATA_SEND 5000 //Per miliseconds
#define MQTT_MAX_PACKET_SIZE 1000

#define NUMBER_OF_STRING 5
#define MAX_STRING_SIZE 50

Dictionary &dict = *(new Dictionary());

static SemaphoreHandle_t barrier;
TaskHandle_t h_listener;

//WiFiClientSecure wifiClient;
WiFiClient wifiClient;
PubSubClient mqttClient(wifiClient);
bool transmit_flag = false;

BLEClient*  pClient;
BLERemoteService* pRemoteService;

bool topic_flag = false; //0 = smartdesk / 1 = smartroom

String uuid_val;
String id_val;
String uuid_event;
String event_str;

typedef struct message {
  char device_uuid_val[37];
  char service_uuid_val[37];
  char char_uuid_val[37];
  char employee_id_val[55];
} message_t;

typedef struct event {
  char device_uuid_val[37];
  char service_uuid_val[37];
  char char_uuid_val[37];
  char event_status_val[37];
  char event_time_val[37];
} event_t;

// Create the struct
message_t msg;
event_t evt;

// MQTT Callback Data
static char messageMacAddress[18];
static char deviceMacAddress[18];

// The remote service we wish to connect to.
//0000180a-0000-1000-8000-00805f9b34fb
//e54b0001-67f5-479e-8711-b3b99198ce6c
//A9A5941D-1681-14E8-E243-78685AB7D125
//E54B0001-67F5-479E-8711-B3B99198CE6C
//e0:5a:5a:c8:36:ac
//3c:71:bf:f5:5d:58
//94:B9:7E:E4:7F:90
//08:3A:F2:6E:10:2C
//3C:71:BF:F5:5D:58

BLEUUID device_uuid("");
BLEUUID service_uuid("");
BLEUUID char_uuid("");

bool doConnect = false;
bool connected = false;
bool doScan = false;
BLERemoteCharacteristic* pRemoteCharacteristic;
BLEAdvertisedDevice* myDevice;

void notifyCallback(
  BLERemoteCharacteristic* pBLERemoteCharacteristic,
  uint8_t* pData,
  size_t length,
  bool isNotify) {
  Serial.print("Notify callback for characteristic ");
  Serial.print(pBLERemoteCharacteristic->getUUID().toString().c_str());
  Serial.print(" of data length ");
  Serial.println(length);
  Serial.print("data: ");
  Serial.println((char*)pData);
}

class MyClientCallback : public BLEClientCallbacks {
    void onConnect(BLEClient* pclient) {
    }

    void onDisconnect(BLEClient* pclient) {
      connected = false;
      Serial.println("onDisconnect");
    }
};

bool connectToServer() {
  Serial.print("Forming a connection to ");
  Serial.println(myDevice->getAddress().toString().c_str());


  //Serial.println(" - Created client");
  pClient  = BLEDevice::createClient();

  pClient->setClientCallbacks(new MyClientCallback());

  // Connect to the remove BLE Server.
  pClient->connect(myDevice);  // if you pass BLEAdvertisedDevice instead of address, it will be recognized type of peer device address (public or private)
  Serial.println(" - Connected to server");

  // Obtain a reference to the service we are after in the remote BLE server.
  pRemoteService = pClient->getService(service_uuid);
  //BLERemoteService* pRemoteService = pClient->getService(serviceUUID);
  if (pRemoteService == nullptr) {
    Serial.print("Failed to find our service UUID: ");
    Serial.println(service_uuid.toString().c_str());
    pClient->disconnect();
    return false;
  }
  Serial.println(" - Found our service");


  // Obtain a reference to the characteristic in the service of the remote BLE server.
  pRemoteCharacteristic = pRemoteService->getCharacteristic(char_uuid);
  if (pRemoteCharacteristic == nullptr) {
    Serial.print("Failed to find our characteristic UUID: ");
    Serial.println(char_uuid.toString().c_str());
    pClient->disconnect();
    return false;
  }
  Serial.println(" - Found our characteristic");

  // Read the value of the characteristic.
  if (pRemoteCharacteristic->canRead()) {
    std::string value = pRemoteCharacteristic->readValue();
    Serial.print("The characteristic value was: ");
    Serial.println(value.c_str());
  }

  if (pRemoteCharacteristic->canNotify())
    pRemoteCharacteristic->registerForNotify(notifyCallback);

  connected = true;
  return true;
}

/**
   Scan for BLE servers and find the first one that advertises the service we are looking for.
*/
class MyAdvertisedDeviceCallbacks: public BLEAdvertisedDeviceCallbacks {
    /**
        Called for each advertising BLE server.
    */
    void onResult(BLEAdvertisedDevice advertisedDevice) {
      Serial.print("BLE Advertised Device found: ");
      Serial.println(advertisedDevice.toString().c_str());
      //Serial.print("Was looking for uuid:");
      //Serial.print(device_uuid);

      // We have found a device, let us now see if it contains the service we are looking for.
      if (advertisedDevice.haveServiceUUID() && advertisedDevice.isAdvertisingService(device_uuid)) {
        Serial.print("===Found ESL with matching device UUID==");
        BLEDevice::getScan()->stop();
        myDevice = new BLEAdvertisedDevice(advertisedDevice);
        doConnect = true;
        doScan = true;

      } // Found our server
    } // onResult
}; // MyAdvertisedDeviceCallbacks

void reconnectToTheBroker() {
  int numberOfConnectionsTried = 0;
  while (!mqttClient.connected()) {
    Serial.println("Reconnecting to MQTT Broker..");
    if (mqttClient.connect(CLIENT_ID, MQTT_USER_NAME, MQTT_PASSWORD)) {
      Serial.println("MQTT Broker Connected.");
      digitalWrite(MQTT_LED, HIGH);
      //subscribe to topic
      mqttClient.subscribe("/name");
      mqttClient.subscribe("/next-event");
    }
    else {
      //MQTT Could not reconnect, wifi/esp32 error
      Serial.print("Connection failed, rc=");
      digitalWrite(MQTT_LED, LOW);
      Serial.print(mqttClient.state());
      numberOfConnectionsTried++;
      if (numberOfConnectionsTried > 5) {
        Serial.print("Rebooting the device...");
        ESP.restart();
      }
    }
    delay(500);
  }
}

void connectToWiFi() {
  WiFi.begin(WIFI_SSID, WIFI_PASSWORD);
  while (WiFi.status() != WL_CONNECTED) {
    delay(500);
  }
  Serial.print("Connected to the WiFi.");

}


void callback(char* topic, byte* payload, unsigned int length) {

  Serial.print("Callback - ");
  Serial.print("Message:");

  char messageTemp[MAX_STRING_SIZE * NUMBER_OF_STRING];
  for (int i = 0; i < length; i++) {
    Serial.print((char)payload[i]);
    messageTemp[i] = payload[i];
  }
  messageTemp[length] = '\0';
  Serial.print("\n");

  const char *delimeter = ";";

  /* -- Getting MacAddresses from both Device and Message -- */
  strcpy(messageMacAddress, strtok(messageTemp, delimeter));
  String getMAC = WiFi.macAddress();
  strcpy(deviceMacAddress, getMAC.c_str());

  Serial.print("deviceMacAddress: ");
  Serial.println(deviceMacAddress);

  if (strcmp(messageMacAddress, deviceMacAddress) == 0) {
    //smart desk
    if (strcmp(topic, "/name") == 0) {
      topic_flag = false;
      Serial.println("Detected message at the topic name");
      strcpy(msg.device_uuid_val, strtok(NULL, delimeter));
      strcpy(msg.service_uuid_val, msg.device_uuid_val);
      msg.service_uuid_val[7] = '1';
      strcpy(msg.char_uuid_val, msg.device_uuid_val);
      msg.char_uuid_val[7] = '2';
      strcpy(msg.employee_id_val, strtok(NULL, delimeter));

      Serial.print("Device uuid: "); Serial.println(msg.device_uuid_val);
      Serial.print("Service uuid: "); Serial.println(msg.service_uuid_val);
      Serial.print("Characteristic uuid: "); Serial.println(msg.char_uuid_val);
      Serial.print("Employee ID: "); Serial.println(msg.employee_id_val);

      uuid_val = msg.device_uuid_val;
      id_val = msg.employee_id_val;
      if (dict[uuid_val] != id_val) {
        //dict(uuid_val, id_val);
        // Transmit the message data to queue.
        transmit_flag = true;
      } else {
        Serial.println("The charactheristic was the same... Doing nothing...");
      }
    }
    //room reservation
    else if (strcmp(topic, "/next-event") == 0) {
      topic_flag = true;
      Serial.println("Detected message at the topic name");
      strcpy(evt.device_uuid_val, strtok(NULL, delimeter));
      strcpy(evt.service_uuid_val, evt.device_uuid_val);
      evt.service_uuid_val[7] = '1';
      strcpy(evt.char_uuid_val, evt.device_uuid_val);
      evt.char_uuid_val[7] = '2';
      strcpy(evt.event_status_val, strtok(NULL, delimeter));
      strcpy(evt.event_time_val, strtok(NULL, delimeter));

      Serial.print("Device uuid: "); Serial.println(evt.device_uuid_val);
      Serial.print("Service uuid: "); Serial.println(evt.service_uuid_val);
      Serial.print("Characteristic uuid: "); Serial.println(evt.char_uuid_val);
      Serial.print("Event Status: "); Serial.println(evt.event_status_val);
      Serial.print("Event Time: "); Serial.println(evt.event_time_val);


      char* temp;
      uuid_event = evt.device_uuid_val;
      temp = strcat(evt.event_status_val, "^");
      event_str = strcat(temp, evt.event_time_val);
      if (dict[uuid_event] != event_str) {
        // Transmit the message data to queue.
        transmit_flag = true;
      } else {
        Serial.println("The charactheristic was the same... Doing nothing...");
      }


    }
  }
  else {
    Serial.println("Different device");
  }
}

void setupMQTT() {
  //wifiClient.setCACert(ca_cert);
  mqttClient.setServer(MQTT_SERVER_NAME, MQTT_PORT);
  // set the callback function
  mqttClient.setCallback(callback);
  mqttClient.setKeepAlive(60);
}


// TODO

// Connect to broker.
// Take the data package.
// Parse it.
// Add to the queue struct.
// Signal to the BLE Task.
static void listener_task(void *argp)
{
  BaseType_t rc;
  for (;;)
  {
    // Connect to broker
    if (!mqttClient.connected()) {
      Serial.println("Reconnecting to the broker..");
      reconnectToTheBroker();
    }
    // Take the data package, parse it.
    mqttClient.loop();

    if (transmit_flag == true)
    {
      transmit_flag = false;

      Serial.println("Giving the semaphore..");
      // Signal to ble_task
      rc = xSemaphoreGive(barrier);
      // assert(rc == pdPASS);

    }
  }
}

// TODO

// Take the queue values.
// Scan the ESL devices.
// Connect to ESL according to the UUID value in the Queue.
// Send the data package. (If the data is bigger than 20 bytes then send it respectively.)
// Disconnect from device.
// Signal to the listener task.
static void ble_task(void *argp)
{
  BaseType_t s;
  BaseType_t rc;

  for (;;)
  {
    rc = xSemaphoreTake(barrier, portMAX_DELAY);
    assert(rc == pdPASS);
    Serial.println("Taking the semaphore..");

    // Transmit to BLEUUID
    if (topic_flag) {
      device_uuid = BLEUUID(evt.device_uuid_val);
      service_uuid = BLEUUID(evt.service_uuid_val);
      char_uuid = BLEUUID(evt.char_uuid_val);
    }
    else {
      device_uuid = BLEUUID(msg.device_uuid_val);
      service_uuid = BLEUUID(msg.service_uuid_val);
      char_uuid = BLEUUID(msg.char_uuid_val);
    }


    // Scan the BLE devices.
    BLEScan* pBLEScan = BLEDevice::getScan();

    // Connect to ESL according to the UUID value in the Queue.
    pBLEScan->setAdvertisedDeviceCallbacks(new MyAdvertisedDeviceCallbacks());

    delay(1000);

    pBLEScan->setInterval(1349);
    pBLEScan->setWindow(449);
    pBLEScan->setActiveScan(true);
    pBLEScan->start(15, false);

    if (doConnect == true) {
      if (connectToServer()) {
        Serial.println("We are now connected to the BLE Server.");
        digitalWrite(BLE_LED, HIGH);
      } else {
        Serial.println("We have failed to connect to the server; there is nothin more we will do.");
        Serial.println(mqttClient.publish("/warning", "{ \"mac\": \"3C:71:BF:F5:5D:58\",\"warningExp\": \"ShelfLabel - abrupt disconnect\", \"warningCode\": 3 }"));
        dict(uuid_val, "error");
        digitalWrite(BLE_LED, LOW);
        digitalWrite(WAR_LED, HIGH);
        delay(250);
        digitalWrite(WAR_LED, LOW);
        delay(250);
        digitalWrite(WAR_LED, HIGH);
        delay(250);
        digitalWrite(WAR_LED, LOW);
      }

      doConnect = false;
    } else {
      Serial.println("doConnect = false");


      Serial.println(mqttClient.publish("/warning", "{ \"mac\": \"3C:71:BF:F5:5D:58\",\"warningExp\": \"ShelfLabel - UUID not found\", \"warningCode\": 2 }"));
      dict(uuid_val, "error");
      digitalWrite(BLE_LED, LOW);
      digitalWrite(WAR_LED, HIGH);
      delay(500);
      digitalWrite(WAR_LED, LOW);
    }

    if (connected) {
      String newString = "";
      if (topic_flag) {
        newString = event_str;
        dict(uuid_event, event_str);
        Serial.println(newString);
        pRemoteCharacteristic->writeValue(newString.c_str(), newString.length());

      }
      else {
        if (sizeof(msg.employee_id_val) > 20) {
          char temp[20] = {0};
          strncpy(temp, msg.employee_id_val, 20);
          temp[19] = '.';
          newString = temp;
          newString.replace(" ", "^");

        } else {
          newString = msg.employee_id_val;
          newString.replace(" ", "^");
        }
        Serial.println("Setting new characteristic value..");
        newString.replace("ğ", "g");
        newString.replace("ç", "c");
        newString.replace("ü", "u");
        newString.replace("ö", "o");
        newString.replace("ş", "s");
        newString.replace("Ğ", "G");
        newString.replace("Ç", "C");
        newString.replace("Ü", "U");
        newString.replace("Ö", "O");
        newString.replace("Ş", "S");
        Serial.println(newString);
        dict(uuid_val, id_val);
        pRemoteCharacteristic->writeValue(newString.c_str(), newString.length());
        //}



        //          //20+ char
        //          char temp[20] = {0};
        //          int i;
        //          int msg_num = strlen(msg.employee_id_val) / 20;
        //          Serial.println(msg_num);
        //          for (i = 0; i < (msg_num + 1); i++) {
        //            //strncpy(temp, msg.employee_id_val,20);
        //            memcpy(temp, &msg.employee_id_val[i * 20], 20);
        //            //Serial.println(temp);
        //            if (i == msg_num) {
        //              temp[strlen(msg.employee_id_val) % 20] = '#';
        //            }
        //            newString = temp;
        //            newString.replace(" ", "^");
        //            Serial.println("Setting new characteristic value..");
        //            Serial.println(newString);
        //            dict(uuid_val, id_val);
        //            pRemoteCharacteristic->writeValue(newString.c_str(), newString.length());
        //            delay(10000);
        //          }

        //else {
        //  Serial.println("The charactheristic was the same... Doing nothing...");
        //}
      }

      // Set the characteristic's value to be the array of bytes that is actually a string.
      //pRemoteCharacteristic->writeValue(newString.c_str(), newString.length());
      pClient->disconnect();
      digitalWrite(BLE_LED, LOW);
    }
  }
}

void setup()
{
  pinMode(MQTT_LED, OUTPUT);
  digitalWrite(MQTT_LED, LOW);
  pinMode(BLE_LED, OUTPUT);
  digitalWrite(BLE_LED, LOW);
  pinMode(WAR_LED, OUTPUT);
  digitalWrite(WAR_LED, LOW);

  int app_cpu = xPortGetCoreID();
  BaseType_t rc;

  barrier = xSemaphoreCreateBinary();
  assert(barrier);

  Serial.begin(115200);
  connectToWiFi();
  setupMQTT();
  Serial.println("Starting Arduino BLE Client application...");
  BLEDevice::init("");

  delay(2000);  // Allow USB to connect

  rc = xTaskCreatePinnedToCore(
         listener_task,
         "listenertask",
         10000,            // Stack Size
         nullptr,
         1,               // Priortiy
         &h_listener,     // Task Handle
         app_cpu          // CPU
       );
  assert(rc == pdPASS);
  assert(h_listener);

  rc = xTaskCreatePinnedToCore(
         ble_task,
         "bletask",
         10000,   // Stack Size
         nullptr,
         1,      // Priortiy
         nullptr,     // Task Handle
         app_cpu // CPU
       );
  assert(rc == pdPASS);
}

void loop()
{
  vTaskDelete(nullptr);
}

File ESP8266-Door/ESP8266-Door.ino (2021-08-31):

#include <Arduino.h>
//This code is for Meeting or Kitchen ESP32s Scanning Gateway
//Topic list included in - https://docs.google.com/document/d/1uNCvFoLJsAC_Qh4L8_6ozjhal6APVGUYTeoTuyXoGE8/edit?usp=sharing

//Device MAC Address: F4:CF:A2:EF:B9:9E

//MQTT and WiFi
//#include <WiFiClientSecure.h>
#include <ESP8266WiFi.h>
#include <PubSubClient.h>
#include <WiFiManager.h>

#include "NeoPixel.h"
#define NEOPIXEL_PIN 13 //D7
#define PIXEL_COUNT 24
#include <Adafruit_NeoPixel.h>
Adafruit_NeoPixel strip = Adafruit_NeoPixel(PIXEL_COUNT, NEOPIXEL_PIN, NEO_GRB + NEO_KHZ800);
NeoPixel DoorLight;

//WiFi reset pin
#define RESET_PIN 12 //d6

//LED for debug
#define WIFI_INFO_LED 4 //d2
//If we are using Onboard leds we cant connect anything to D0 and D4/
#define ONBOARD_LED1 16 //Reversed LOW = HIGH //D0 //Near the power
#define ONBOARD_LED2 2 //Reversed LOW = HIGH //D4 //Near the antenna

#define DATA_SEND_DELAY 5000 //Per miliseconds
#define MQTT_MAX_PACKET_SIZE 1000
//#define ONBOARD_LED 2 //Onboard LED used for debugging.

//Callback
#define NUMBER_OF_STRING 4
#define MAX_STRING_SIZE 40

//Change Config File to Connect the MQTT Broker
#include "MQTT_Config.h"

unsigned long lastSendTime = 0;


//WiFiClientSecure wifiClient;
WiFiClient wifiClient;
PubSubClient mqttClient(wifiClient);
WiFiManager wm;

uint8_t message_char_buffer[MQTT_MAX_PACKET_SIZE];
char deviceMacAddress[18];
char CLIENT_ID[18];
char APName[25];

void setAPandWiFiName() {
  String getMAC = WiFi.macAddress();
  strcpy(deviceMacAddress, getMAC.c_str());
  strcpy(CLIENT_ID, deviceMacAddress);
  String getAPName = "Fora - ";
  getAPName += WiFi.macAddress() ;
  strcpy(APName, getAPName.c_str());
}

/*void connectToWiFi() {
  WiFi.mode(WIFI_STA);
  WiFi.begin(WIFI_SSID, WIFI_PASSWORD);
  while (WiFi.status() != WL_CONNECTED) {
    digitalWrite(ONBOARD_LED, LOW);
    delay(500);
    digitalWrite(ONBOARD_LED, HIGH);
  }
  Serial.print("Connected to the WiFi.");
  digitalWrite(ONBOARD_LED, LOW);
  }*/

void connectToWiFi() {
  /* char APName[28];
    String getAPName = "ESP8266 - ";
    getAPName += WiFi.macAddress() ;
    strcpy(APName, getAPName.c_str());*/
  WiFi.mode(WIFI_STA);
  if (WiFi.status() != WL_CONNECTED) {
    wm.setConnectTimeout(300);
    wm.setConfigPortalTimeout(120);
    bool res = wm.autoConnect(APName, "academy2021");
    if (!res) {
      digitalWrite(WIFI_INFO_LED, LOW);
      Serial.println("Failed to connect");
      ESP.restart;
    }
    else {
      digitalWrite(WIFI_INFO_LED, HIGH);
      Serial.println("connected to wifi");
    }
  }
}


void callback(char* topic, byte* payload, unsigned int length) {


  //strcpy(DeviceMacAdress,WiFi.macAddress());

  digitalWrite(ONBOARD_LED2, LOW);
  delay(500);
  digitalWrite(ONBOARD_LED2, HIGH);
  Serial.print("Callback - ");
  Serial.print("Message:");
  //String messageTemp;
  char messageTemp[MAX_STRING_SIZE * NUMBER_OF_STRING];
  for (int i = 0; i < length; i++) {
    Serial.print((char)payload[i]);
    //messageTemp += (char)payload[i];
    //strcat(messageTemp,(char)payload[i]);
    messageTemp[i] = payload[i];
  }
  messageTemp[length] = '\0';
  Serial.print("\n");

  char *delimeter = ";";

  /* -- Getting MacAddresses from both Device and Message -- */
  char messageMacAddress[17];
  strcpy(messageMacAddress, strtok(messageTemp, delimeter));
  /*  char deviceMacAddress[18];
    String getMAC = WiFi.macAddress();
    strcpy(deviceMacAddress, getMAC.c_str());*/

  char UUID[32];
  char eventStatus[10];
  char eventTime[6];
  int numOfPeopleInTheRoom = 0;
  int capacityOfRoom = 0;

  if (strcmp(messageMacAddress, deviceMacAddress) == 0) {
    // Check if the MQTT message was received on topic esp32/relay1
    if (strcmp(topic, "/nrom") == 0) {
      Serial.println("Detected message at the topic nrom");
      numOfPeopleInTheRoom = atoi(strtok(NULL, delimeter));
      capacityOfRoom = atoi(strtok(NULL, delimeter));

      uint32_t orange = strip.Color(255, 69, 0);
      uint32_t black = strip.Color(0, 0, 0);
      uint32_t blue = strip.Color(0, 0, 255);
      uint32_t red = strip.Color(255, 0, 0);
      //changeLedStatusCalculateCapacity(orange, black, red, numOfPeopleInTheRoom, capacityOfRoom);
      DoorLight.changeLedStatusOneLedPerPerson(orange, black, red, numOfPeopleInTheRoom, capacityOfRoom);

      Serial.print("numOfPeopleInTheRoom: "); Serial.println(numOfPeopleInTheRoom);
    }
    if (strcmp(topic, "/next-event/yusuf") == 0) {
      Serial.println("Detected message at the topic next-event");
      strcpy(UUID, strtok(NULL, delimeter));
      strcpy(eventStatus, strtok(NULL, delimeter));
      strcpy(eventTime, strtok(NULL, delimeter));

      Serial.print("UUID: "); Serial.println(UUID);
      Serial.print("eventStatus: "); Serial.println(eventStatus);
      Serial.print("eventTime: "); Serial.println(eventTime);
    }
  }
  else {
    Serial.println("Different device");
  }

}

void setupMQTT() {
  //wifiClient.setCACert(ca_cert);
  mqttClient.setServer(MQTT_SERVER_NAME, MQTT_PORT);
  // set the callback function
  mqttClient.setCallback(callback);
  mqttClient.setKeepAlive(60);
}


void setup() {
  Serial.begin(9600);
  setAPandWiFiName();
  connectToWiFi();
  setupMQTT();
  DoorLight.setupNeoPixel();
  setupIO();
}

void setupIO() {
  pinMode(RESET_PIN, INPUT_PULLUP);
  pinMode(WIFI_INFO_LED, OUTPUT);
  pinMode(ONBOARD_LED1, OUTPUT);
  pinMode(ONBOARD_LED2, OUTPUT);
  digitalWrite(WIFI_INFO_LED, LOW);
  digitalWrite(ONBOARD_LED1, HIGH);
  digitalWrite(ONBOARD_LED2, HIGH);
}
void checkButton() {
  // check for button press
  if ( digitalRead(RESET_PIN) == HIGH ) {
    delay(50);
    if ( digitalRead(RESET_PIN) == HIGH ) {
      //disconnect from wifi and open config portal
      Serial.println("Button Pressed");
      digitalWrite(WIFI_INFO_LED, LOW);
      digitalWrite(ONBOARD_LED1, HIGH);
      // start portal
      Serial.println("Starting config portal");
      wm.resetSettings();
      Serial.println("Resetting recorded creditentials");
      wm.setConfigPortalTimeout(180);

      if (!wm.startConfigPortal(APName, "academy2021")) {
        Serial.println("failed to connect or hit timeout");
        digitalWrite(WIFI_INFO_LED, LOW);
        delay(3000);
        ESP.restart();
      } else {
        Serial.println("connected");
        digitalWrite(WIFI_INFO_LED, HIGH);
      }
    }
  }
}
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

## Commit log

2021-08-13 Trying to make the MQTT smaller, currently %117
2021-08-14 Now we can acess the scan result from the main file but there is a problem with BLE and WiFi both
    [BLEScanner.cpp]
2021-08-16 First version of filtering / smoothing is added.
2021-08-16 Format update about scanned devices
2021-08-16 Added reboot, MQTT Currently not working properly I think HiveMQ is not working
    [ESP32-Scanner.ino]
2021-08-19 Some code fixes, now beacon can be seen.
    [BLEScanner.cpp, ESP8266-Door.ino]
2021-08-24 Added warning log publish in case of timeout
2021-08-24 Added temperature and humidity functionality.
2021-08-24 Added circuit diagrams for easy installation.
    [ESP32-Scanner.fzz, ESP8266-NoLevelConverter.fzz, ESP8266-WithLevelConverter.fzz]
2021-08-25 Fixed MQTT Data problem, added MQTTDebugger
    [ESP32-Scanner.ino]
2021-08-26 Fixed some warnings in the code.
    [ESP32-Scanner.ino]
2021-08-26 Fixed json problem, again...
    [ESP32-Scanner.ino]
2021-08-26 added LED monitor for MQTT
2021-08-28 added led on off
2021-08-28 Added some quick prototype pcb tests.
2021-08-29 Added some quick pcb test software
2021-08-30 Improved PCB Tester
2021-08-31 Added remote wifi control and led for debug
2021-09-08 Updated all connections schematics to new versions.
    [ESP32-Scanner.fzz, ESP32-ShelfLabelController.fzz, ESP8266-NoLevelConverter.fzz]
2021-09-09 Added all the box desings.
    [BordaLogo.ipt, CR2450.ipt, Door-BottomPart.0004.ipt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]
2021-09-09 Desing to Design fix.
    [BordaLogo.ipt, CR2450.ipt, Door-BottomPart.0004.ipt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]
